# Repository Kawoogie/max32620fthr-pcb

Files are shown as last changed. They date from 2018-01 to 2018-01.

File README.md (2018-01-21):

# MAX32620FTHR PCB CAD Data

## Files
File Name | Description
--- | ---
max32620fthr.brd  | Cadsoft Eagle Board File (7.5.0)
max32620fthr.sch  | Cadsoft Eagle Schematic File (7.5.0)
output-gerb274x_4layer.cam  | Cadsoft Eagle CAM Job (7.5.0)
output/max32620fthr.gpi  | Photoplotter Info File
output/max32620fthr.GTL  | Top (1) copper
output/max32620fthr.GTS  | Top soldermask
output/max32620fthr.GTO  | Top silk screen
output/max32620fthr.GTP  | Top paste
output/max32620fthr.G2L  | Inner GND (2) copper
output/max32620fthr.G3L  | Inner PWR (15) copper
output/max32620fthr.GBL  | Bottom (16) copper
output/max32620fthr.GBS  | Bottom soldermask
output/max32620fthr.GBO  | Bottom silk screen
output/max32620fthr.GFD  | Fab drawing
output/max32620fthr.GML  | Mill Layer
output/max32620fthr.dri  | Drill Station Info File
output/max32620fthr.TXT  | Excellon Drill File
output/max32620fthr.mnt  | Component XY Data File
output/max32620fthr_sch.pdf  | PDF Schematic
output/max32620fthr_fab.PDF  | PDF Fab Drawing

## Bill Of Materials
[Octopart MAX32620FTHR BOM](https://octopart.com/bom-tool/neiQ2i4s)

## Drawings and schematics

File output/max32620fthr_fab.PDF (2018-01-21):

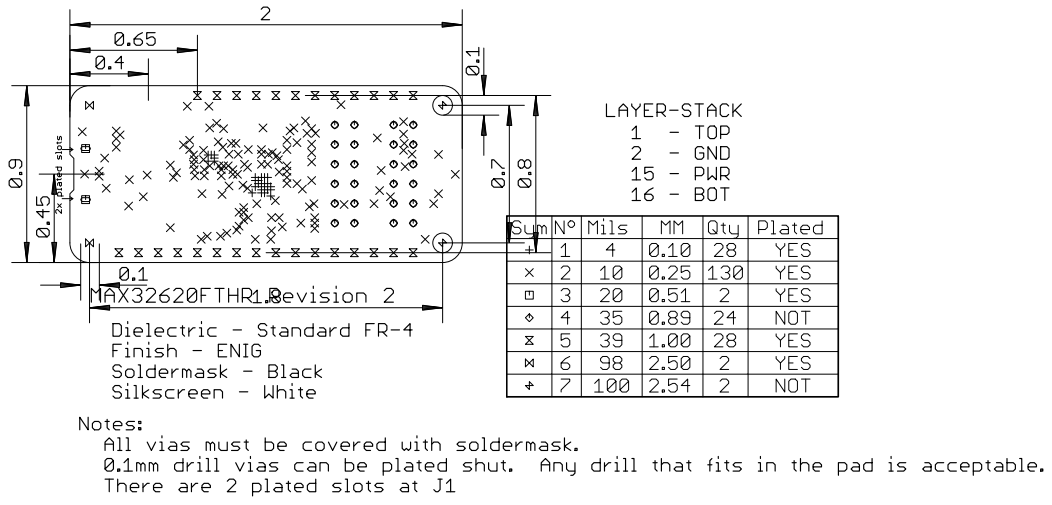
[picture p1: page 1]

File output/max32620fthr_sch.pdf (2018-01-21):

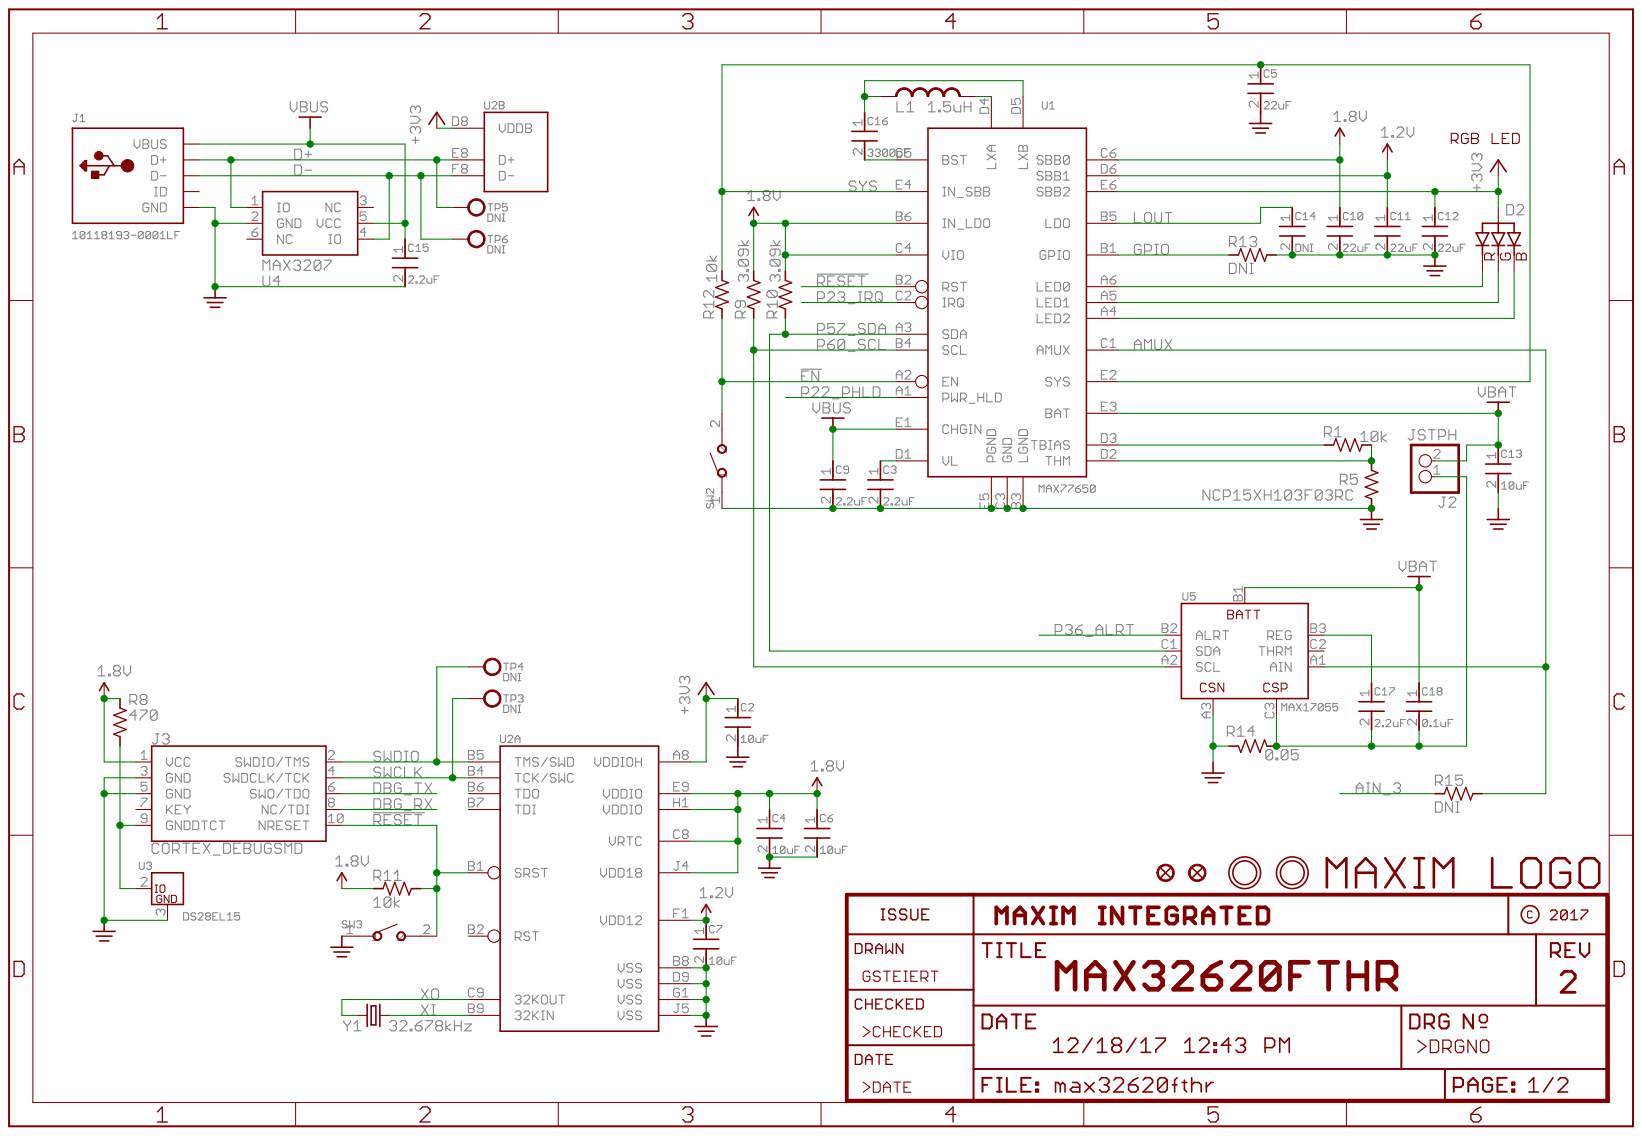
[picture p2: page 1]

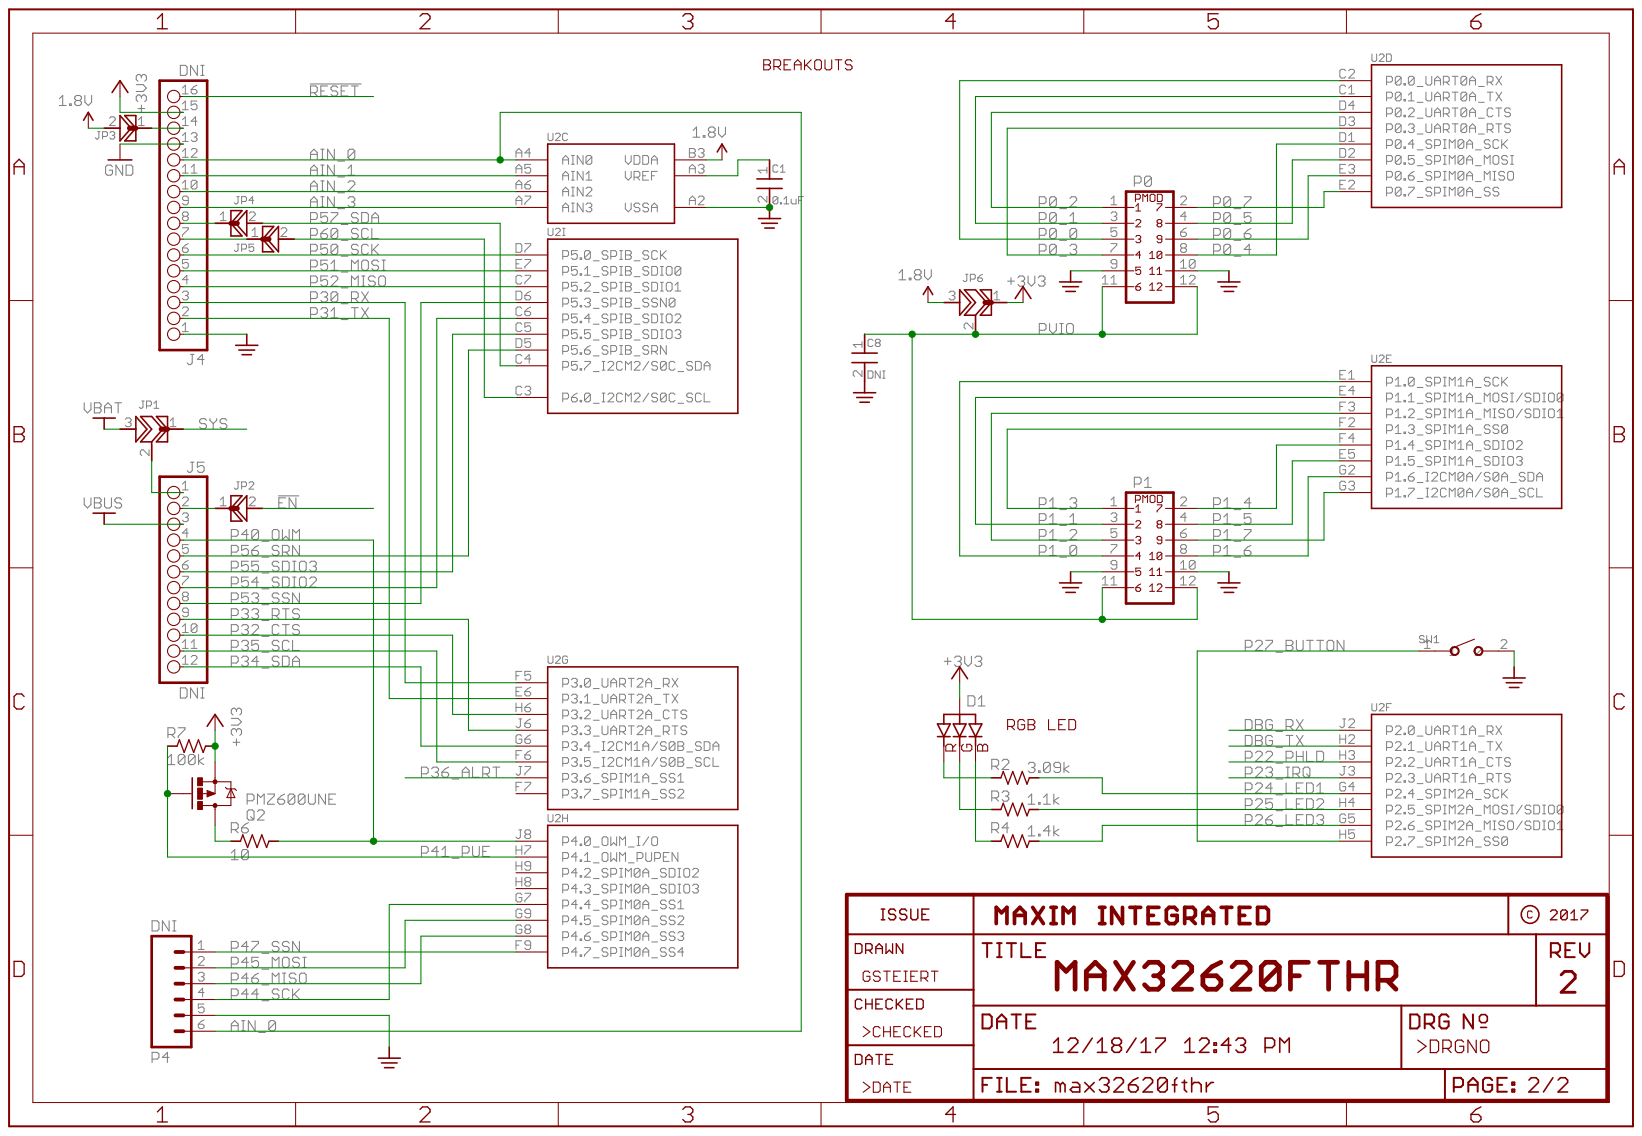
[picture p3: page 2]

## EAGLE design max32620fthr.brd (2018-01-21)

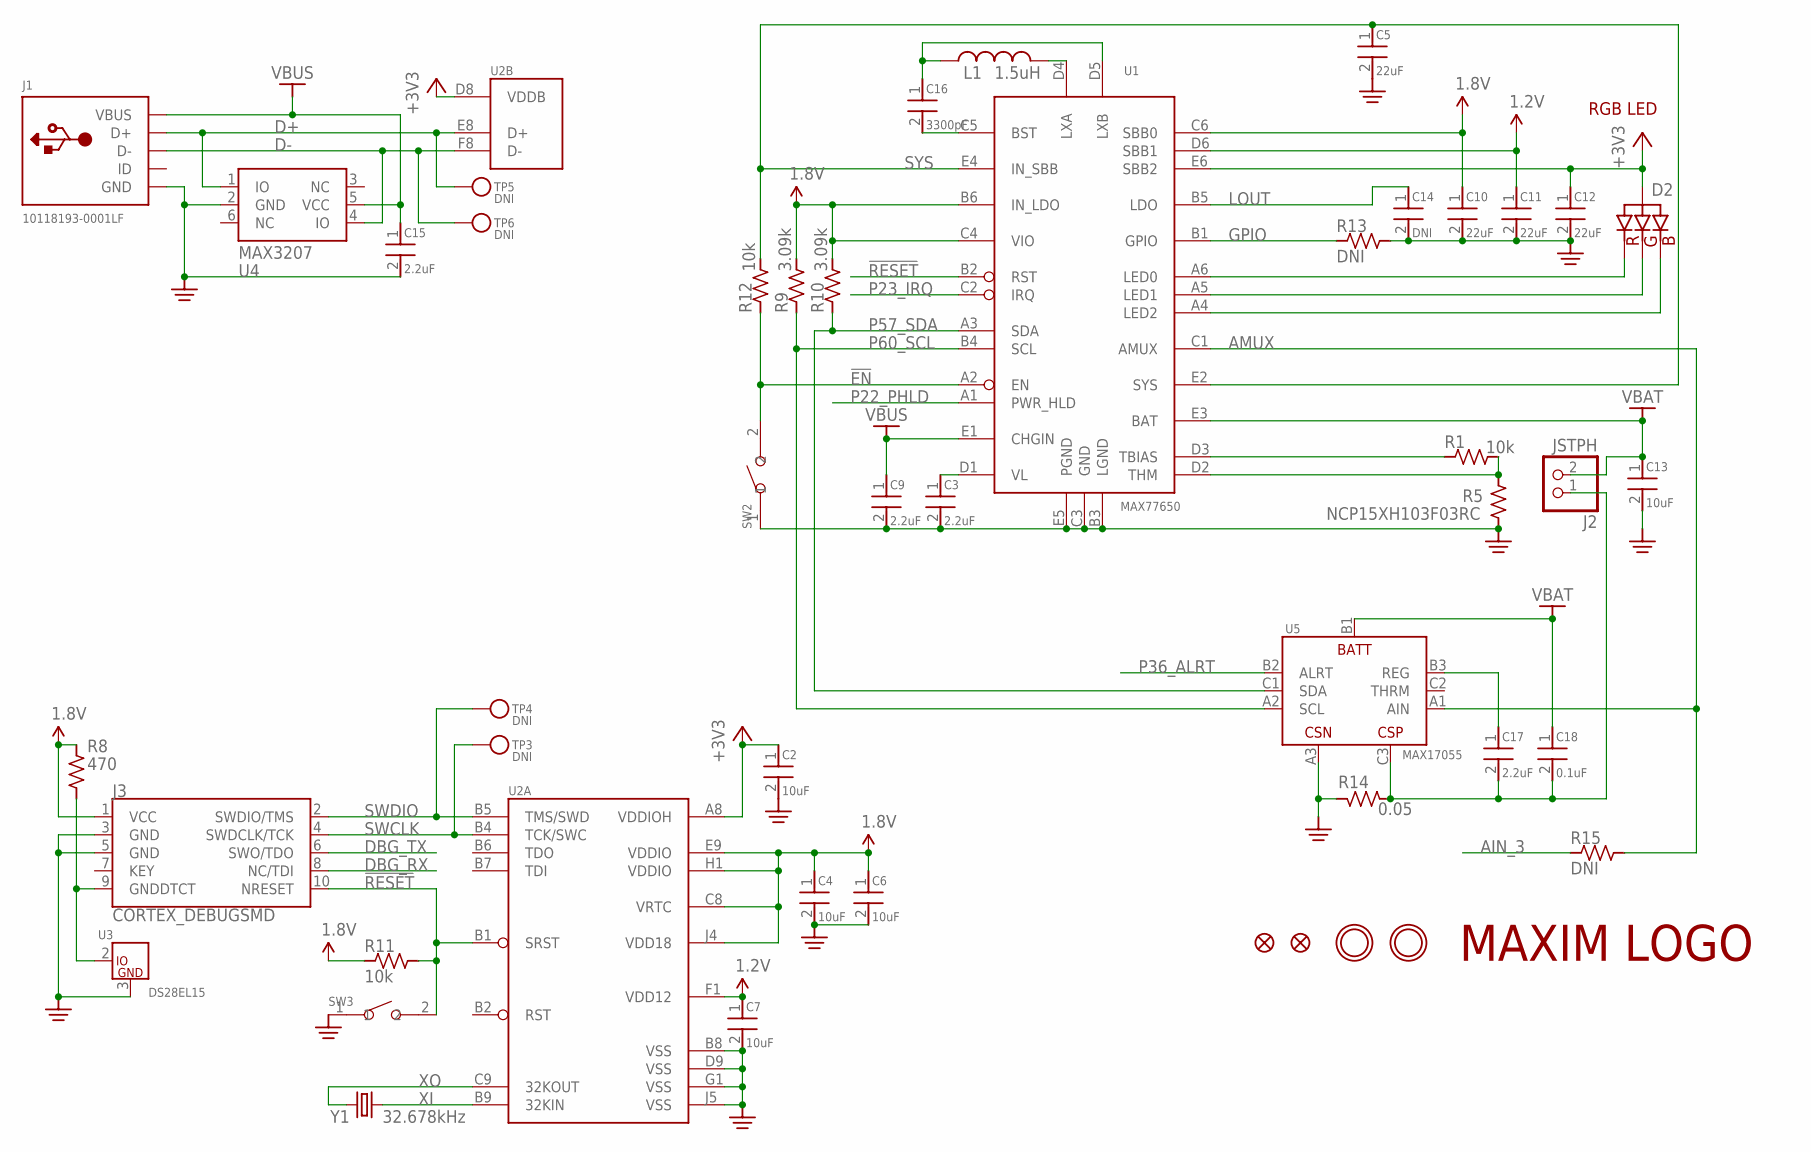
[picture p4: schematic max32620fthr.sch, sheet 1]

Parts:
C2, C4, C6, C7, C13: 10uF; 0402
C3, C9, C15, C17: 2.2uF; 0402
C5, C10, C11, C12: 22uF; 0402
C14: DNI; 0402
C16: 3300pF; 0402
C18: 0.1uF; 0402
D2: RGBLED_CALUMIX-SML-LX0404; LUMIX-SML-LX0404
J1: 10118193-0001LF; MICRO-USB5+6P-SMD-0.65-B
J2: JSTPH; JSTPH2
J3: CORTEX_DEBUGSMD; SAMTECH_FTSH-105-01
L1: 1.5uH; IND2016
R1, R11, R12: 10k; 0402
R5: NCP15XH103F03RC; 0402
R8: 470; 0402
R9, R10: 3.09k; 0402
R13, R15: DNI; 0402
R14: 0.05; 0402
SW2, SW3: SMD-BUTTON(2P-3.0X2.5X1.2+0.4MM)-B3U-1000P-2P-SMD; SW2-2.6-3.0X2.5X1.2+0.4MM
TP3, TP4, TP5, TP6: DNI; TESTPOINT_ROUND_1MM
U1: MAX77650; W302H2-1
U2: MAX32620; W813D3-1
U3: DS28EL15; T633-2
U4: MAX3207; SOT23-6
U5: MAX17055; W91N1-1
U$3: DNI; MXM_LOGO_6MM
U$31, U$32: DNI; MOUNTINGHOLE_2.5_PLATED
U$34, U$35: DNI; FIDUCIAL_1MM
Y1: 32.678kHz; FC-12M

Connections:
1.2V: C7.1, C11.1, U1.D6 (SBB1), U2.F1 (VDD12)
1.8V: C4.1, C6.1, C10.1, J3.1 (VCC), R8.2, R9.2, R10.2, R11.1, U1.B6 (IN_LDO), U1.C4 (VIO), U1.C6 (SBB0), U2.C8 (VRTC), U2.E9 (VDDIO), U2.H1 (VDDIO), U2.J4 (VDD18); also elsewhere on the board
!EN: R12.1, SW2.2, U1.A2 (EN); also elsewhere on the board
!RESET: J3.10 (NRESET), R11.2, SW3.2, U1.B2 (RST), U2.B1 (SRST); also elsewhere on the board
+3V3: C2.1, C12.1, D2.1 (VCC), U1.E6 (SBB2), U2.A8 (VDDIOH), U2.D8 (VDDB); also elsewhere on the board
AIN_3: R15.1; also elsewhere on the board
AMUX: R15.2, U1.C1 (AMUX), U5.A1 (AIN)
D+: J1.3 (D+), TP5.P$1, U2.E8 (D+), U4.1 (IO)
D-: J1.2 (D-), TP6.P$1, U2.F8 (D-), U4.4 (IO)
DBG_RX: J3.8 (NC/TDI); also elsewhere on the board
DBG_TX: J3.6 (SWO/TDO); also elsewhere on the board
GND: C2.2, C3.2, C4.2, C5.2, C6.2, C7.2, C9.2, C10.2, C11.2, C12.2, C13.2, C14.2, C15.2, J1.5 (GND), J1.S1 (GND), J1.S2 (GND), J1.S3 (GND), J1.S4 (GND), J1.S5 (GND), J1.S6 (GND), J3.3 (GND), J3.5 (GND), R5.2, R13.2, R14.2, SW2.1, SW3.1, U1.B3 (LGND), U1.C3 (GND), U1.E5 (PGND), U2.B8 (VSS), U2.D9 (VSS), U2.G1 (VSS), U2.J5 (VSS), U3.3 (GND), U4.2 (GND), U5.A3 (CSN); also elsewhere on the board
GPIO: R13.1, U1.B1 (GPIO)
LOUT: C14.1, U1.B5 (LDO)
unnamed: D2.2 (RED), U1.A6 (LED0)
unnamed: D2.4 (GREEN), U1.A5 (LED1)
unnamed: D2.3 (BLUE), U1.A4 (LED2)
unnamed: C3.1, U1.D1 (VL)
unnamed: R1.2, R5.1, U1.D2 (THM)
unnamed: R1.1, U1.D3 (TBIAS)
unnamed: J3.9 (GNDDTCT), R8.1, U3.2 (IO)
unnamed: C17.2, C18.2, J2.1, R14.1, U5.C3 (CSP)
unnamed: C17.1, U5.B3 (REG)
unnamed: C16.2, U1.C5 (BST)
unnamed: C16.1, L1.1, U1.D5 (LXB)
unnamed: L1.2, U1.D4 (LXA)
P22_PHLD: U1.A1 (PWR_HLD); also elsewhere on the board
P23_IRQ: U1.C2 (IRQ); also elsewhere on the board
P36_ALRT: U5.B2 (ALRT); also elsewhere on the board
P57_SDA: R10.1, U1.A3 (SDA), U5.C1 (SDA); also elsewhere on the board
P60_SCL: R9.1, U1.B4 (SCL), U5.A2 (SCL); also elsewhere on the board
SWCLK: J3.4 (SWDCLK/TCK), TP3.P$1, U2.B4 (TCK/SWC)
SWDIO: J3.2 (SWDIO/TMS), TP4.P$1, U2.B5 (TMS/SWD)
SYS: C5.1, R12.2, U1.E2 (SYS), U1.E4 (IN_SBB); also elsewhere on the board
VBAT: C13.1, C18.1, J2.2, U1.E3 (BAT), U5.B1 (BATT); also elsewhere on the board
VBUS: C9.1, C15.1, J1.1 (VBUS), U1.E1 (CHGIN), U4.5 (VCC); also elsewhere on the board
XI: U2.B9 (32KIN), Y1.2
XO: U2.C9 (32KOUT), Y1.1

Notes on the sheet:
RGB LED

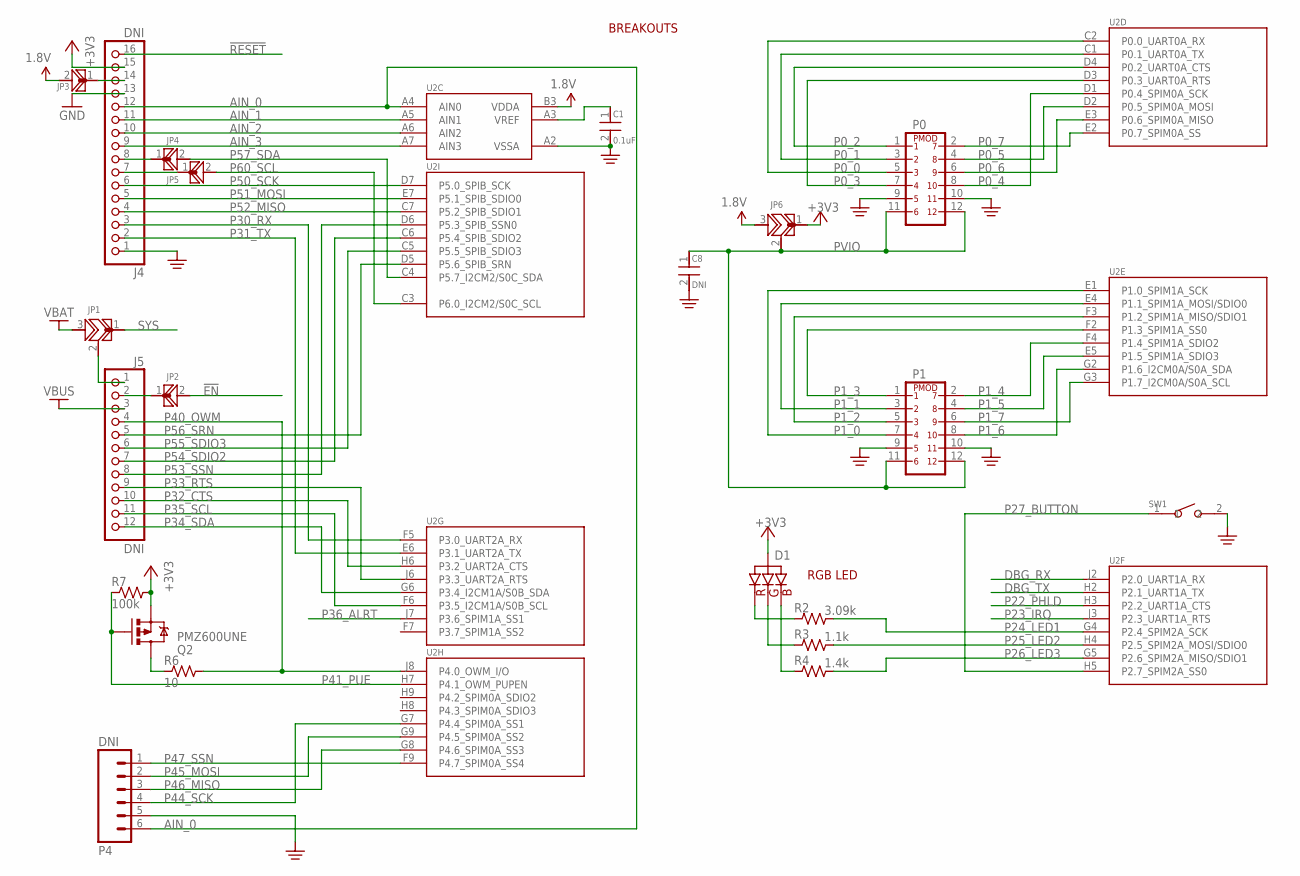
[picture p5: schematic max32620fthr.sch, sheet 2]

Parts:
C1: 0.1uF; 0402
C8: DNI; 0402
D1: RGBLED_CALUMIX-SML-LX0404; LUMIX-SML-LX0404
J4: DNI; 1X16_ROUND
J5: DNI; 1X12_ROUND
JP1, JP6: DNI; SS0402
JP2, JP3, JP4, JP5: DNI; SB0402
P0, P1: PMOD_DUALPASSTHROUGH; 2X6_HLE_BE
P4: DNI; 1X06-SMD_EDGE
Q2: PMZ600UNE; SOT-883
R2: 3.09k; 0402
R3: 1.1k; 0402
R4: 1.4k; 0402
R6: 10; 0402
R7: 100k; 0402
SW1: SMD-BUTTON(2P-3.0X2.5X1.2+0.4MM)-B3U-1000P-2P-SMD; SW2-2.6-3.0X2.5X1.2+0.4MM
U2: MAX32620; W813D3-1

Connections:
1.8V: JP3.2, JP6.3, U2.B3 (VDDA); also elsewhere on the board
!EN: JP2.2; also elsewhere on the board
!RESET: J4.16; also elsewhere on the board
+3V3: D1.1 (VCC), J4.15, JP6.1, Q2.2 (S), R7.2; also elsewhere on the board
AIN_0: J4.12, P4.6, U2.A4 (AIN0)
AIN_1: J4.11, U2.A5 (AIN1)
AIN_2: J4.10, U2.A6 (AIN2)
AIN_3: J4.9, U2.A7 (AIN3); also elsewhere on the board
DBG_RX: U2.J2 (P2.0_UART1A_RX); also elsewhere on the board
DBG_TX: U2.H2 (P2.1_UART1A_TX); also elsewhere on the board
GND: C1.2, C8.2, J4.1, J4.13, P0.9, P0.10, P1.9, P1.10, P4.5, SW1.2, U2.A2 (VSSA); also elsewhere on the board
unnamed: J4.8, JP4.1
unnamed: J4.7, JP5.1
unnamed: J4.14, JP3.1
unnamed: J5.2, JP2.1
unnamed: J5.1, JP1.2
unnamed: D1.2 (RED), R2.1
unnamed: D1.4 (GREEN), R3.1
unnamed: D1.3 (BLUE), R4.1
unnamed: Q2.3 (D), R6.1
unnamed: C1.1, U2.A3 (VREF)
P0_0: P0.5, U2.C2 (P0.0_UART0A_RX)
P0_1: P0.3, U2.C1 (P0.1_UART0A_TX)
P0_2: P0.1, U2.D4 (P0.2_UART0A_CTS)
P0_3: P0.7, U2.D3 (P0.3_UART0A_RTS)
P0_4: P0.8, U2.D1 (P0.4_SPIM0A_SCK)
P0_5: P0.4, U2.D2 (P0.5_SPIM0A_MOSI)
P0_6: P0.6, U2.E3 (P0.6_SPIM0A_MISO)
P0_7: P0.2, U2.E2 (P0.7_SPIM0A_SS)
P1_0: P1.7, U2.E1 (P1.0_SPIM1A_SCK)
P1_1: P1.3, U2.E4 (P1.1_SPIM1A_MOSI/SDIO0)
P1_2: P1.5, U2.F3 (P1.2_SPIM1A_MISO/SDIO1)
P1_3: P1.1, U2.F2 (P1.3_SPIM1A_SS0)
P1_4: P1.2, U2.F4 (P1.4_SPIM1A_SDIO2)
P1_5: P1.4, U2.E5 (P1.5_SPIM1A_SDIO3)
P1_6: P1.8, U2.G2 (P1.6_I2CM0A/S0A_SDA)
P1_7: P1.6, U2.G3 (P1.7_I2CM0A/S0A_SCL)
P22_PHLD: U2.H3 (P2.2_UART1A_CTS); also elsewhere on the board
P23_IRQ: U2.J3 (P2.3_UART1A_RTS); also elsewhere on the board
P24_LED1: R2.2, U2.G4 (P2.4_SPIM2A_SCK)
P25_LED2: R3.2, U2.H4 (P2.5_SPIM2A_MOSI/SDIO0)
P26_LED3: R4.2, U2.G5 (P2.6_SPIM2A_MISO/SDIO1)
P27_BUTTON: SW1.1, U2.H5 (P2.7_SPIM2A_SS0)
P30_RX: J4.3, U2.F5 (P3.0_UART2A_RX)
P31_TX: J4.2, U2.E6 (P3.1_UART2A_TX)
P32_CTS: J5.10, U2.H6 (P3.2_UART2A_CTS)
P33_RTS: J5.9, U2.J6 (P3.3_UART2A_RTS)
P34_SDA: J5.12, U2.G6 (P3.4_I2CM1A/S0B_SDA)
P35_SCL: J5.11, U2.F6 (P3.5_I2CM1A/S0B_SCL)
P36_ALRT: U2.J7 (P3.6_SPIM1A_SS1); also elsewhere on the board
P40_OWM: J5.4, R6.2, U2.J8 (P4.0_OWM_I/O)
P41_PUE: Q2.1 (G), R7.1, U2.H7 (P4.1_OWM_PUPEN)
P44_SCK: P4.4, U2.G7 (P4.4_SPIM0A_SS1)
P45_MOSI: P4.2, U2.G9 (P4.5_SPIM0A_SS2)
P46_MISO: P4.3, U2.G8 (P4.6_SPIM0A_SS3)
P47_SSN: P4.1, U2.F9 (P4.7_SPIM0A_SS4)
P50_SCK: J4.6, U2.D7 (P5.0_SPIB_SCK)
P51_MOSI: J4.5, U2.E7 (P5.1_SPIB_SDIO0)
P52_MISO: J4.4, U2.C7 (P5.2_SPIB_SDIO1)
P53_SSN: J5.8, U2.D6 (P5.3_SPIB_SSN0)
P54_SDIO2: J5.7, U2.C6 (P5.4_SPIB_SDIO2)
P55_SDIO3: J5.6, U2.C5 (P5.5_SPIB_SDIO3)
P56_SRN: J5.5, U2.D5 (P5.6_SPIB_SRN)
P57_SDA: JP4.2, U2.C4 (P5.7_I2CM2/S0C_SDA); also elsewhere on the board
P60_SCL: JP5.2, U2.C3 (P6.0_I2CM2/S0C_SCL); also elsewhere on the board
PVIO: C8.1, JP6.2, P0.11, P0.12, P1.11, P1.12
SYS: JP1.1; also elsewhere on the board
VBAT: JP1.3; also elsewhere on the board
VBUS: J5.3; also elsewhere on the board

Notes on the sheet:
BREAKOUTS
RGB LED

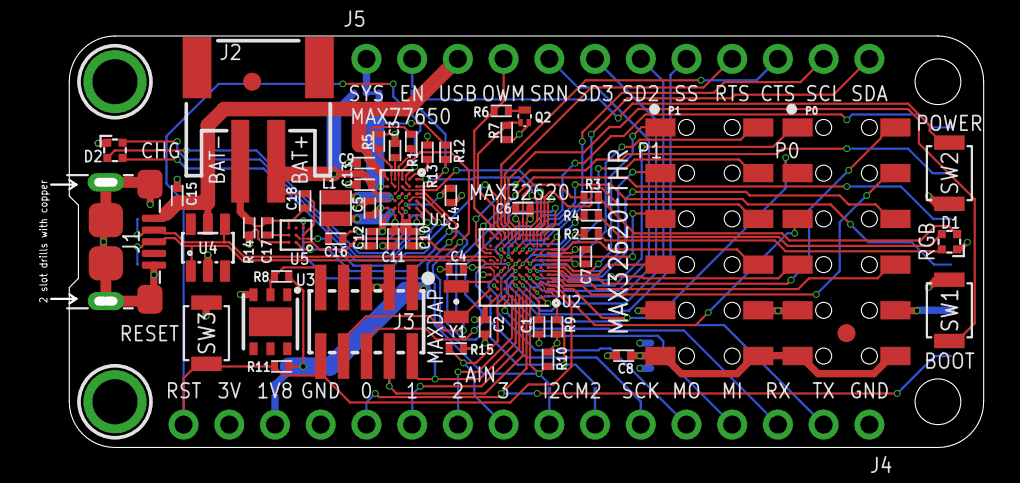
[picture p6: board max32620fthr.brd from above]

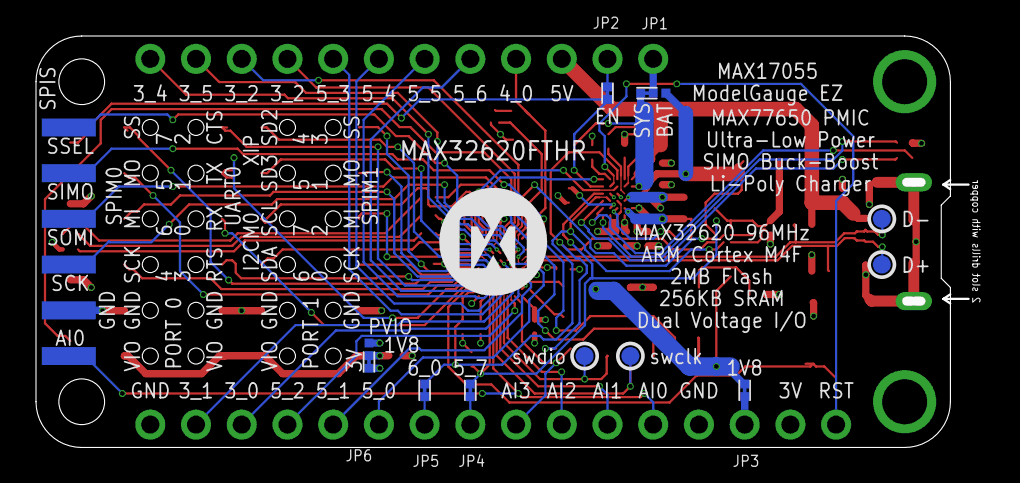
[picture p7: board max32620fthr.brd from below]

Board: 4 copper layers, 51.8 x 22.9 mm, 70 parts (12 on the bottom side), 91 nets.

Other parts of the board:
DRILEGEND: DRILEGEND

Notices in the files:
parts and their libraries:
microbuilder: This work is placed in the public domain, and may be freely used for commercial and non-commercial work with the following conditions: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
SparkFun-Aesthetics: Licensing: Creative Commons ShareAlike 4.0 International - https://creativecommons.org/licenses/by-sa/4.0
